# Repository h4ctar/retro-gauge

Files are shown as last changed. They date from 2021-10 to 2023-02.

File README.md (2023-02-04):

# Retro Gauge

## Introduction

This is an open source motorcycle tacho project with the following features:

- Analog tachometer
- Digital speedometer
- Odometer
- Trip meter
- Battery voltage
- Standard indicators (turn signals, oil pressure, neutral and high beam)
- Clock

It is housed in a classic round casing, with a retro looking 8 digit starburst LCD.

The toolchain is all open source; the PCB's are designed with KiCad and the case is designed in FreeCAD.

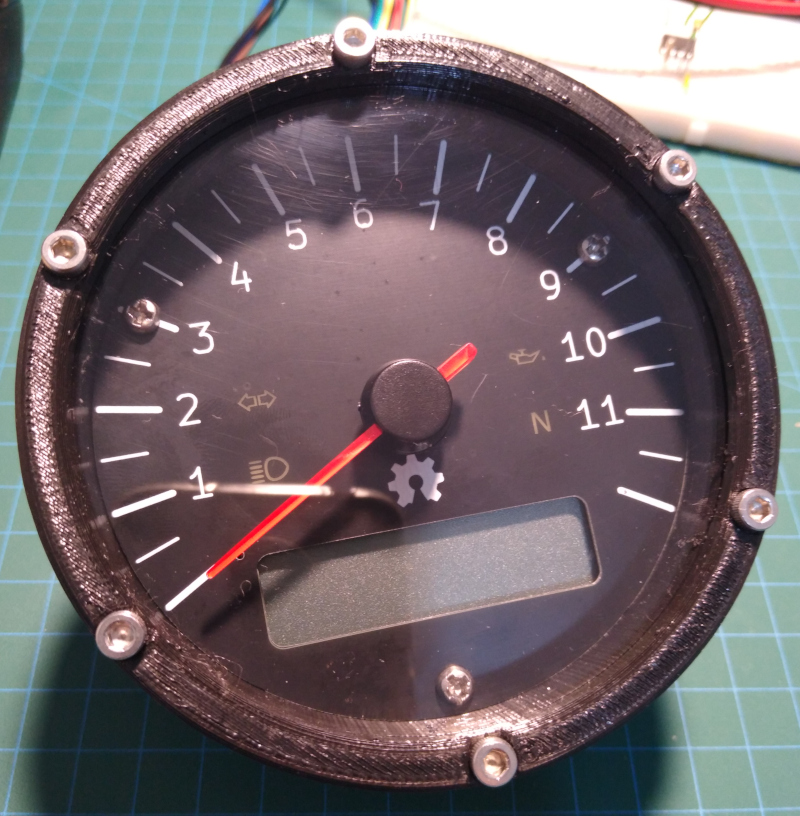
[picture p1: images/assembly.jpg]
Assembly


## System Design

The system design is simple, the only interesting decision is that the indicators all go via the microcontroller, this lets us do fun things with the indicators (test them when powered on or reuse the oil pressure indicator for other warnings).

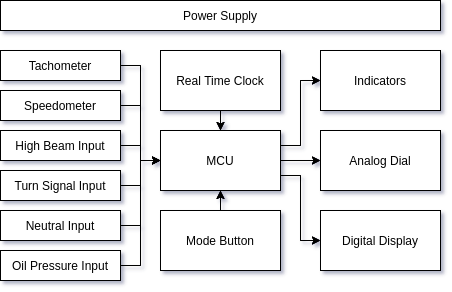
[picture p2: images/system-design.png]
System Design


## Microcontroller

An ATmega328P-PU microcontroller will be used to process all the inputs, and drive the outputs.

Here are all the required inputs and outputs:

| Function | Type | Number of pins |
| --- | --- | --- |
| Tacho | Digital input  | 1 |
| Speedo | Digital input  | 1 |
| Oil pressure | Digital input  | 1 |
| Turn signals | Digital input  | 1 |
| Neutral | Digital input  | 1 |
| High beam | Digital input  | 1 |
| Mode button | Digital input  | 1 |
| Battery voltage | Analog input | 1 |
| Stepper motor | Digital output | 4 (could be 3) |
| RBG LEDs | Digital output | 1 |
| LCD | Digital output | 3 |
| ISP | Digital IO | 3 (can be shared) |
| Real time clock | Digital IO | 2 |

For a total of 18 digital IOs and one analog input, the ATmega328P-PU has more than enough at 23 programmable IO lines.

The ATmega328P-PU also has 1024 bytes of EEPROM which can be used to store the configuration, trip and odometer values.

An external 16 MHz crystal will be used to run the ATmega328P-PU at it's fastest clock speed.

The microcontroller will be programmed with an in-circuit serial programmer (ICSP).
A bootloader doesnt need to be burned when using ICSP.

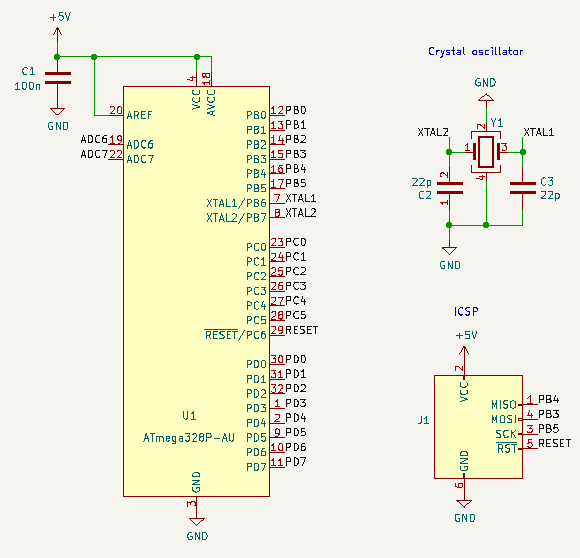
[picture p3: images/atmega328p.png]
ATmega328P


The low byte fuses configure the clock:

| Bit | Name | Description | Value |
| --- | --- | --- | ----- |
| 7 | CKDIV8 | When set, divides the clock speed by 8 | 1 |
| 6 | CKOUT  | When set, the clock pulse is output on PB0 | 1 |
| 5 | SUT1 | Sets start up delay time | 1 |
| 4 | SUT0 | | 1 |
| 3 | CKSEL3 | Sets the clock source | 1 |
| 2 | CKSEL2 | | 1 |
| 1 | CKSEL1 | | 1 |
| 0 | CKSEL0 | | 1 |

The high byte fuses:

| Bit | Name | Description | Value |
| --- | --- | --- | ----- |
| 7 | RSTDISBL | External reset disable | 1 |
| 6 | DWEN | Debug wire enable | 1 |
| 5 | SPIEN | Enable serial programming | 0 |
| 4 | WDTON | Watchdog timer always on | 1 |
| 3 | EESAVE | Preserve EEPROM memory through chip erase | 0 |
| 2 | EBOOTSZ1 | Sets the bootloder size memory | 1 |
| 1 | EBOOTSZ0 | | 1 |
| 0 | BOOTRST  | Select the reset vector | 0 |

The extended fuses:

| Bit | Name | Description | Value |
| --- | --- | --- | ----- |
| 7 | | Not used | 1 |
| 6 | | | 1 |
| 5 | | | 1 |
| 4 | | | 1 |
| 3 | | | 1 |
| 2 | BODLEVEL2 | Sets the brown-out detector level | 1 |
| 1 | BODLEVEL1 | | 0 |
| 0 | BODLEVEL0 | | 1 |

There is a simple Makefile that compiles and links the code and has targets to burn the fuses and the code.

## Power Supply

A linear voltage regulator will be used to convert the bikes rough 14V down to a smooth 5V for the rest of the system.
A smoothing capacitor is added on the bikes side to help smooth out the input before it gets to the regulator.

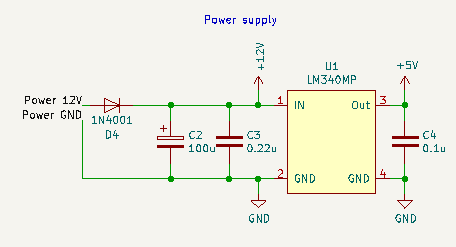
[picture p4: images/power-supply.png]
Power Supply


## Indicator Lights

There are indicator lights for low oil pressure, neutral, high beam and turn signals.

The oil pressure and neutral sensors are simple switches to ground.
So these will be directly connected to digital input pins.
I'm not sure if the internal pull ups will be good enough so there will be provision on the PCB for external pull up resistors.
There will be a diode to protect against connecting this pin to 12V on the bike.

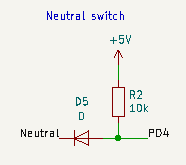
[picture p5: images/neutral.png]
Neutral


The highbeam and turn signals indicators should light up when they see 12V.
We'll use an optocoupler to give some extra protection.
The left and right turn signals need to go through diodes to stop them turning each other on.

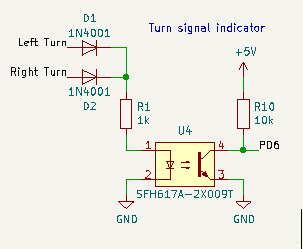
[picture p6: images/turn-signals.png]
Turn Signals


```
Diode forward voltage: 0.715V
Photodiode forward voltage: 1.3V
Photodiode forward current: 10mA
R1 = (14V - 0.715V - 1.3V) / 10mA = 1200 ohm ~= 1k ohm
```

```
CTR: 50%
Output current: 50% of 10mA = 5mA
Output voltage: 4V
R2 = (5V - 4V) / 5mA = 200 ohm
```

## Tachometer

There are a few choices for the tachometer pickup, an inductive or capacitive pickup on one of the spark plug wires, or a hall effect sensor on a rotating part of the engine.
The most robust solution is to go with the hall effect sensor, and the most universal location for it is in replacement of the mechanical drive off the camshaft of the original tachometer.

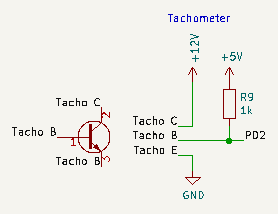
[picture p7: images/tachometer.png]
Tachometer


## Speedometer

The speedometer will also be a hall effect pickup, but will be a simpler design with a few magnets on the wheel and an NPN hall effect sensor mounted on an axel spacer.

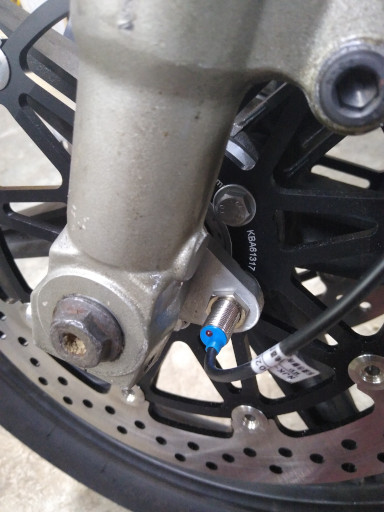
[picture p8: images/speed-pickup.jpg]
Speed Pickup


## Real Time Clock

A PCF8563T RTC module will be used to keep the time for the clock.
It will have a coin cell to keep the clock ticking when the key is off.

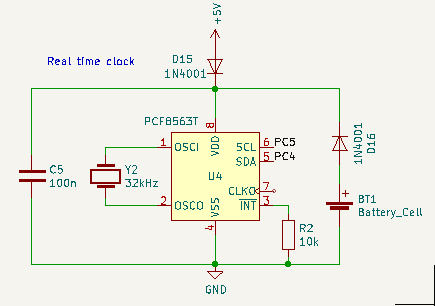
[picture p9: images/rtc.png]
RTC


## LCD

The VIM-878-DP-FC-S-LV LCD display will be used.
It is a transflective LCD so works well in both bright sunlight and at night with a backlight.
It is an 8 character 14 (plus 2) segment "starburst" display.
It has a total of (14 + 2) \* 8 = 128 segments and uses 4 backplanes.

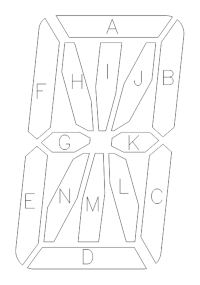
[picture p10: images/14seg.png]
LCD Segment Names


The HT1621B will be used to drive the LCD.
There are some existing Arduino libraries to interface with it.
It can drive 32 segments by 4 commons which is exactly what is required to drive the selected LCD.

The schematic of the driver to the display follows the application notes in the datasheet and is optimised for the PCB layout.
It is controlled with 3 pins that are also used by the ICSP.

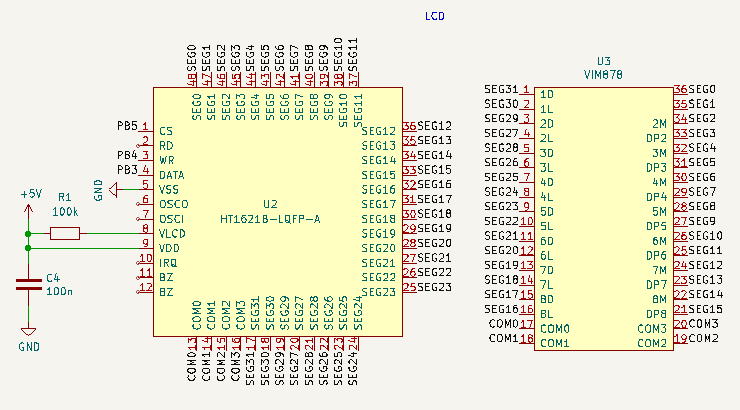
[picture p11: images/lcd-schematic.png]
LCD Schematic


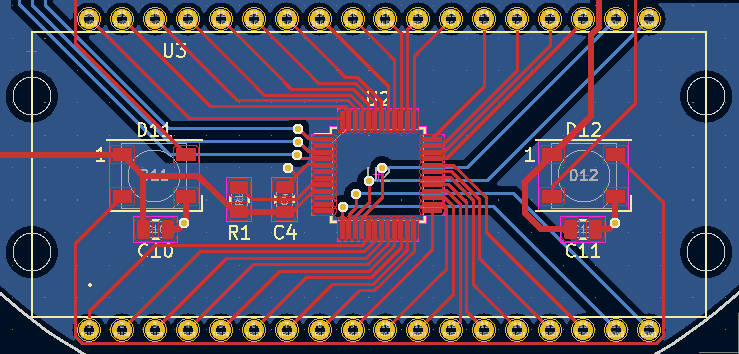
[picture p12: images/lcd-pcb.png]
LCD PCB


This table has the LCD segments from the datasheet and what memory address they are according to the PCB layout:

| LCD Pin | COM0 | COM1 | COM2 | COM3 | Memory address |
| --- | ---- | ---- | ---- | ---- | --- |
| 1 | 1D | 1E | 1F | CA1  | 31 |
| 2 | 1L | 1K | 1J | 1I | 30 |
| 3 | 2D | 2E | 2F | CA2  | 29 |
| 4 | 2L | 2K | 2J | 2I | 27 |
| 5 | 3D | 3E | 3F | CA3  | 28 |
| 6 | 3L | 3K | 3J | 3I | 26 |
| 7 | 4D | 4E | 4F | CA4  | 25 |
| 8 | 4L | 4K | 4J | 4I | 24 |
| 9 | 5D | 5E | 5F | CA5  | 23 |
| 10 | 5L | 5K | 5J | 5I | 22 |
| 11 | 6D | 6E | 6F | CA6  | 21 |
| 12 | 6L | 6K | 6J | 6I | 20 |
| 13 | 7D | 7E | 7F | CA7  | 19 |
| 14 | 7L | 7K | 7J | 7I | 18 |
| 15 | 8D | 8E | 8F | CA8  | 17 |
| 16 | 8L | 8K | 8J | 8I | 16 |
| 17 | COM0 | | | | |
| 18 | | COM1 | | | |
| 19 | | | COM2 | | |
| 20 | | | | COM3 | |
| 21 | DP8  | 8C | 8B | 8A | 15 |
| 22 | 8M | 8N | 8G | 8H | 14 |
| 23 | DP7  | 7C | 7B | 7A | 13 |
| 24 | 7M | 7N | 7G | 7H | 12 |
| 25 | DP6  | 6C | 6B | 6A | 11 |
| 26 | 6M | 6N | 6G | 6H | 10 |
| 27 | DP5  | 5C | 5B | 5A | 9 |
| 28 | 5M | 5N | 5G | 5H | 8 |
| 29 | DP4  | 4C | 4B | 4A | 7 |
| 30 | 4M | 4N | 4G | 4H | 6 |
| 31 | DP3  | 3C | 3B | 3A | 5 |
| 32 | 3M | 3N | 3G | 3H | 4 |
| 33 | DP2  | 2C | 2B | 2A | 3 |
| 34 | 2M | 2N | 2G | 2H | 2 |
| 35 | DP1  | 1C | 1B | 1A | 1 |
| 36 | 1M | 1N | 1G | 1H | 0 |

From this table we can see that each digit is powered by 4 LCD pins that map to 4 memory addresses.
For example digit 1 is LCD pins 35, 1, 2 and 36, which map to memory address' 1, 31, 30 and 0.

The font maps ASCII characters to the segments in order CA,F,E,D,I,J,K,L,A,B,C,DP,H,G,N,M.
The segments are in this order so the nibbles match the memory layout of the driver.

The address mapping maps digits to the 4 memory addresses that the font nibbles should be written to.

| Digit | Address' |
| ----- | --- |
| 1 |  1,31,30, 0|
| 2 |  3,29,27, 2|
| 3 |  5,28,26, 4|
| 4 |  7,25,24, 6|
| 5 |  9,23,22, 8|
| 6 | 11,21,20,10|
| 7 | 13,19,18,12|
| 8 | 15,17,16,14|

This font table and address mapping should be enough to display text on the LCD.

## Stepper motor

The X27.168 stepper motor will be used, it is designed for gauges and can be directly driven from a microcontroller.

People on the internet say that clamping diodes are required, so they will be added.

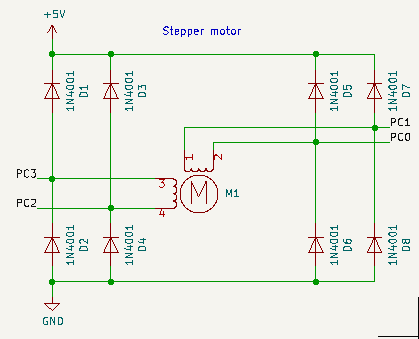
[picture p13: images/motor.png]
Motor


The X25 datasheet shows the required pattern to step the motor.

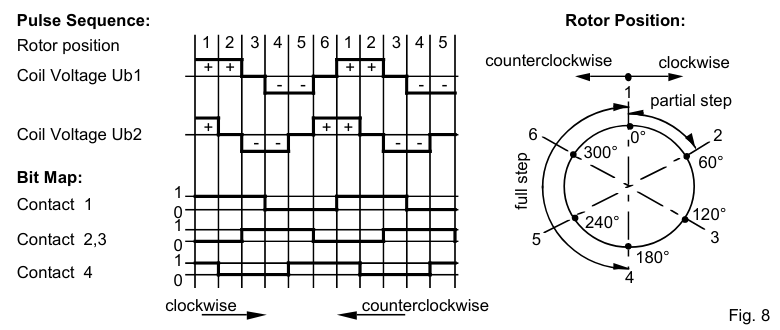
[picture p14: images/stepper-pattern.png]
Step Pattern


## Indicators

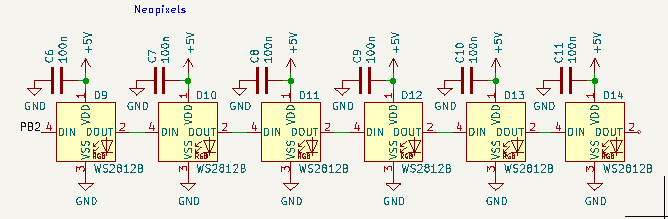
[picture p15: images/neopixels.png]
Neopixels


## PCB Design

There are three PCBs: the main board, the sensor board and the face board.
The boards are stacked using standoffs and are connected together with 2.54mm stacking header pins.

The main board has the microcontroller, stepper motor, LCD, real time clock and indicators.
The sensor board has the power supply and the signal conditioning.
The face board is the dial face and has transparent icons for the indicators.

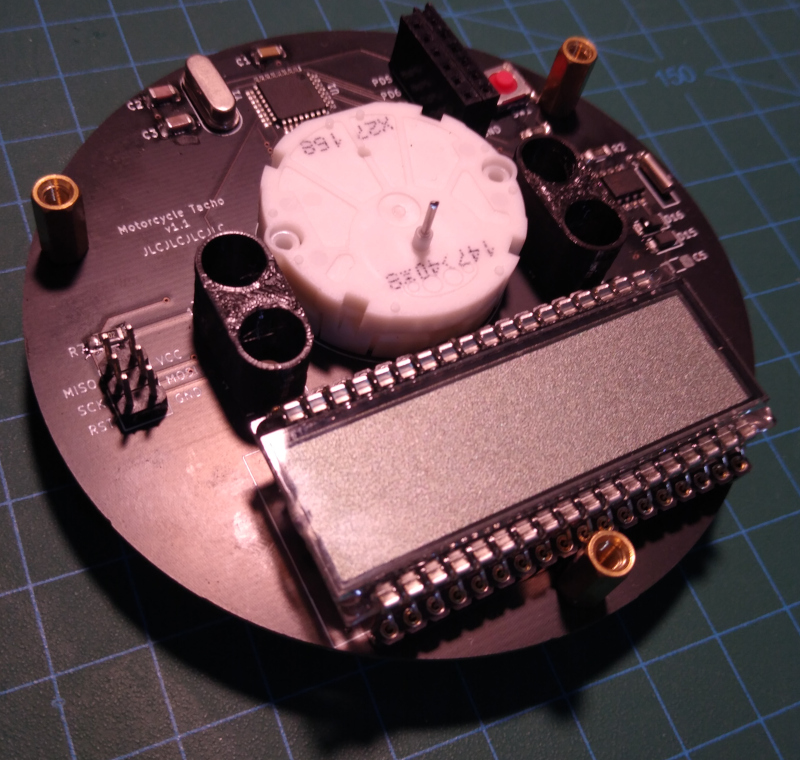
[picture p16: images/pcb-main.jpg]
Main PCB


## Case Design

The case is 3D printed out of ASA.

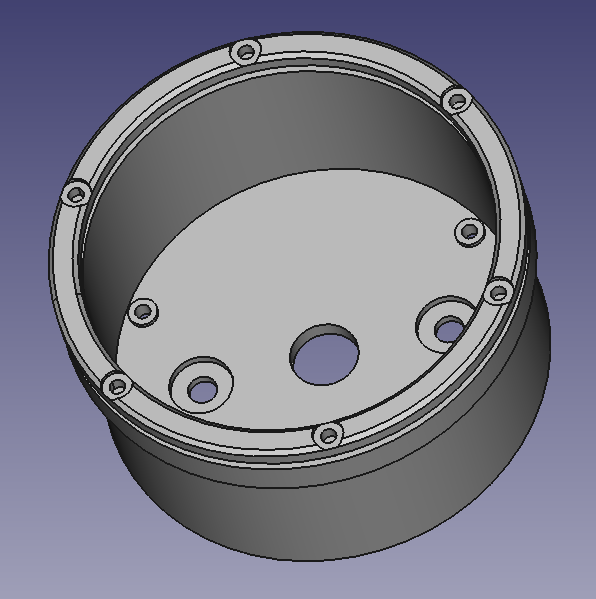
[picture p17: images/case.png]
Case


## EEPROM

The ODO, trip and configuration will be stored in EEPROM.

EEPROM has like 100,000 writes before it wears out, so in order to be able to store the ODO and trip we will need to be able to rotate to new address'.
To do this we will have a table at the start of the EEPROM that stores the address of each value and if the EEPROM gets corrupt we will find a new place to store it and update the table.

| Address | Size | Description |
| --- | ---- | --- |
| 0 | 8 | ODO Address |
| 1 | 8 | Trip Address |
| 2 | 8 | Wheel diameter |
| 15 | 8 | Next available address |
| 16 | 32 | ODO value |
| 20 | 32 | Trip value |

## Firmware

The source code is in the `firmware/src` directory.

There is a makefile with a default target to compile and link the source into a hex file; a `burn` target to burn this hex to the micro and a `fuses` target to write the fuses.
It is configured to use avrdude and a usbtiny programmer to talk to the microcontroller, but it should be possible to modify it to use other methods.
The code is compiled with clang.
There is a compile_flags.txt file that is used to configure a language server so that Vim or Visual Studio Code can give nice completion and code navigation.

On Arch linux I install the following tools and dependencies:

 * llvm
 * clang
 * avrdude
 * avr-libc
 * lib32-glibc

## Datasheets

 * [ATmega328p](https://ww1.microchip.com/downloads/en/DeviceDoc/Atmel-7810-Automotive-Microcontrollers-ATmega328P_Datasheet.pdf)
 * [HT1621B](https://www.holtek.com/documents/10179/116711/HT1621v321.pdf)
 * [WS2812B](https://www.digikey.com.au/en/datasheets/parallaxinc/parallax-inc-28085-ws2812b-rgb-led-datasheet)

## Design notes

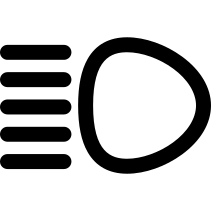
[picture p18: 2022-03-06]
images/indicators/high-beam-svgrepo-com.png

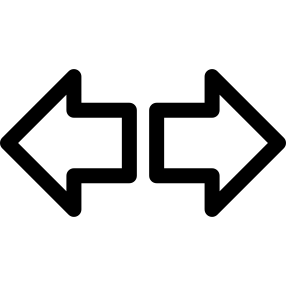
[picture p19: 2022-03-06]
images/indicators/turn-signals-svgrepo-com.png

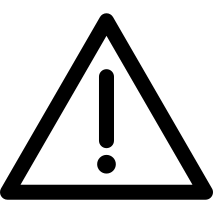
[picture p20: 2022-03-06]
images/indicators/warning-svgrepo-com-1.png

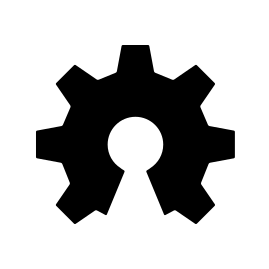
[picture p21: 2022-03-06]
images/indicators/oshw.png

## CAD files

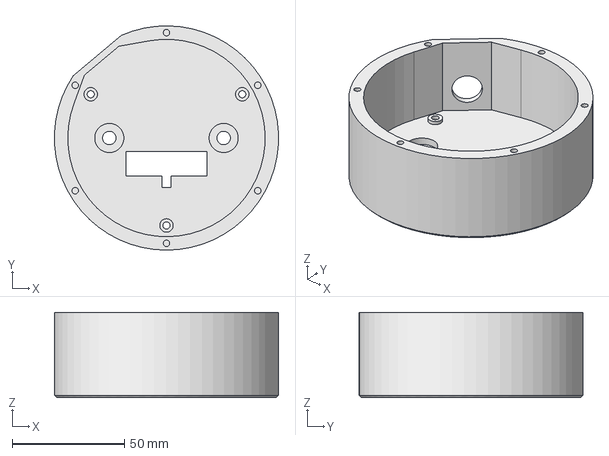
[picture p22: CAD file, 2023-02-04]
3d-models/case.FCStd
99.9 x 100.0 x 38.0 mm

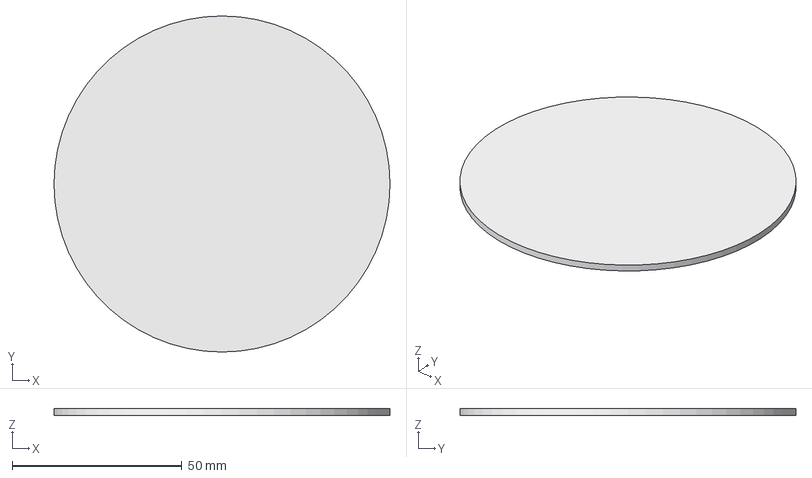
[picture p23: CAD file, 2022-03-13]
3d-models/glass.FCStd
99.0 x 99.0 x 2.00 mm

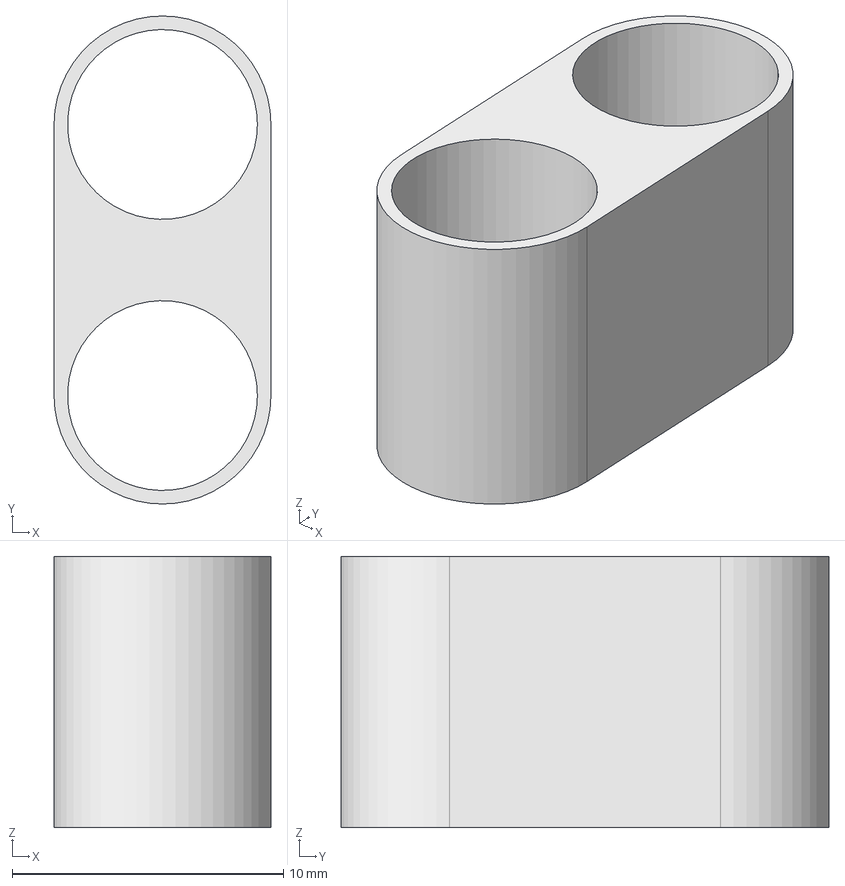
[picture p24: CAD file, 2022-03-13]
3d-models/led-shield.FCStd
8.00 x 18.0 x 10.0 mm

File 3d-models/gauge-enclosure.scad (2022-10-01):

$fn=64;
overlap=0.001;

inner_height=40;
inner_radius=43.5;
wall_thickness=6.5;
base_thickness=4;

standoff_height=2;
standoff_outer_radius=3;

pcb_mounting_hole_radius=1.5;

difference() {
    union() {
        difference() {
            // The main body
            cylinder(inner_height + base_thickness, inner_radius + wall_thickness, inner_radius + wall_thickness);
            // The hole in the middle
            translate([0, 0, base_thickness]) {
                cylinder(inner_height + overlap, inner_radius, inner_radius);
            };
        };
        // The PCB standoffs
        translate([-33.78, 19.2, 0]) {
            cylinder(base_thickness + standoff_height, standoff_outer_radius, standoff_outer_radius);
        };
        translate([33.78, 19.2, 0]) {
            cylinder(base_thickness + standoff_height, standoff_outer_radius, standoff_outer_radius);
        };
        translate([0, -39, 0]) {
            cylinder(base_thickness + standoff_height, standoff_outer_radius, standoff_outer_radius);
        };
    };
    // The face plate screw holes
    for (i = [0 : 60 : 360]) {
        rotate([0, 0, i]) {
            translate([0, 46.5, 32]) {
                cylinder(10, 1.3, 1.3);
            };
        }
    }
    // The PCB screw holes
    translate([-33.78, 19.2, -1]) {
        cylinder(10, pcb_mounting_hole_radius, pcb_mounting_hole_radius);
    };
    translate([33.78, 19.2, -1]) {
        cylinder(10, pcb_mounting_hole_radius, pcb_mounting_hole_radius);
    };
    translate([0, -39, -1]) {
        cylinder(10, pcb_mounting_hole_radius, pcb_mounting_hole_radius);
    };
    // The cable grommet hole
    translate([0, 0, -1]) {
        cylinder(10, 7.5, 7.5);
    };
    translate([0, 0, 1.5]) {
        cylinder(10, 10, 10);
    };
    // The mounting bolt holes
    translate([-26, 0, -1]) {
        cylinder(10, 3, 3);
    };
    translate([-26, 0, 2]) {
        cylinder(10, 6.5, 6.5);
    };
    translate([26, 0, -1]) {
        cylinder(10, 3, 3);
    };
    translate([26, 0, 2]) {
        cylinder(10, 6.5, 6.5);
    };
    // The button hole
    rotate([0, 0, 130]) {
        translate([46.5, 0, 13]) {
            rotate([0, 90, 0]) {
                union() {
                    translate([0, 0, 5]) {
                        cube([100, 18, 4.6], true);
                    };
                    cylinder(10, 6, 6, true);
                    translate([0, 0, -3]) {
                        cube([18, 18, 4], true);
                    };
                };
            };
        };
    };
};   
  

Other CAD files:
3d-models/pcb-outline.FCStd

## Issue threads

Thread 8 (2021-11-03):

Stacking through hole pin headers

h4ctar, 2021-11-03:
Should be a bit lower profile

And it could be easier to trace with the same plug between the face and the main and then sensor pcbs

h4ctar, 2021-11-27:
Done

Closed 2021-11-27.

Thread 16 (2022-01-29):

TWI pull up resistors

h4ctar, 2022-01-29:
https://embedds.com/programming-avr-i2c-interface/

h4ctar, 2022-01-30:
Not needed as there are built in pull ups

Closed 2022-01-30.

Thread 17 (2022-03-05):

Move speedo and tacho to interrupt pins

h4ctar, 2022-03-05:
The speedo is currently done with a pin change interrupt instead of a hardware interrupt.

Change it to one of the two hardware interrupt pins if possible.

Closed 2022-09-17.

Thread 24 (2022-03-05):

Shorter power smoothing capacitor

h4ctar, 2022-03-05:

Closed 2022-03-07.

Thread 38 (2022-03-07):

Bigger RTC backup cell

h4ctar, 2022-03-07:

h4ctar, 2022-03-07:
Currently it has a CR1220 which is 38mAh.
The chip draw 0.25uA in backup.
So the battery will last 16 years, I think this is OK.

Closed 2022-03-07.

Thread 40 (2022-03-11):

Fix 3D models

h4ctar, 2022-03-11:
All 3D models are missing since the upgrade to kicad 6

Closed 2022-09-17.

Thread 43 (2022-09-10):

Speed sensor spikes

h4ctar, 2022-09-10:
When the engine is running the speedo spikes

h4ctar, 2022-09-10:
Fixed by reducing the 10k pull up resistor to 1k.

This will result in a current draw of 5V/1kohm = 5mA which is still fine, the NJK-5002C NPN type hall effect sensor load current is 150mA so it should be able to pull it down.

Closed 2022-09-10.

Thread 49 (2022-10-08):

Fix octocoupler footprint

h4ctar, 2022-10-08:

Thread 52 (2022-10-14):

Fix crystal oscillator wiring

h4ctar, 2022-10-14:

h4ctar, 2022-10-14:
The wrong pins are used.
It needs a ground.
Should only be 9pF.

h4ctar, 2022-10-14:
Actually, maybe they should be 12pF.

Closed 2022-10-14.

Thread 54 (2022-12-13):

Create pipeline

h4ctar, 2022-12-13:
Create a GitHub pipeline to:
- Generate STL from FreeCad models
- Generate BOM
- Generate POS
- Generate Gerbers
- Generate Drill
- Build ELF

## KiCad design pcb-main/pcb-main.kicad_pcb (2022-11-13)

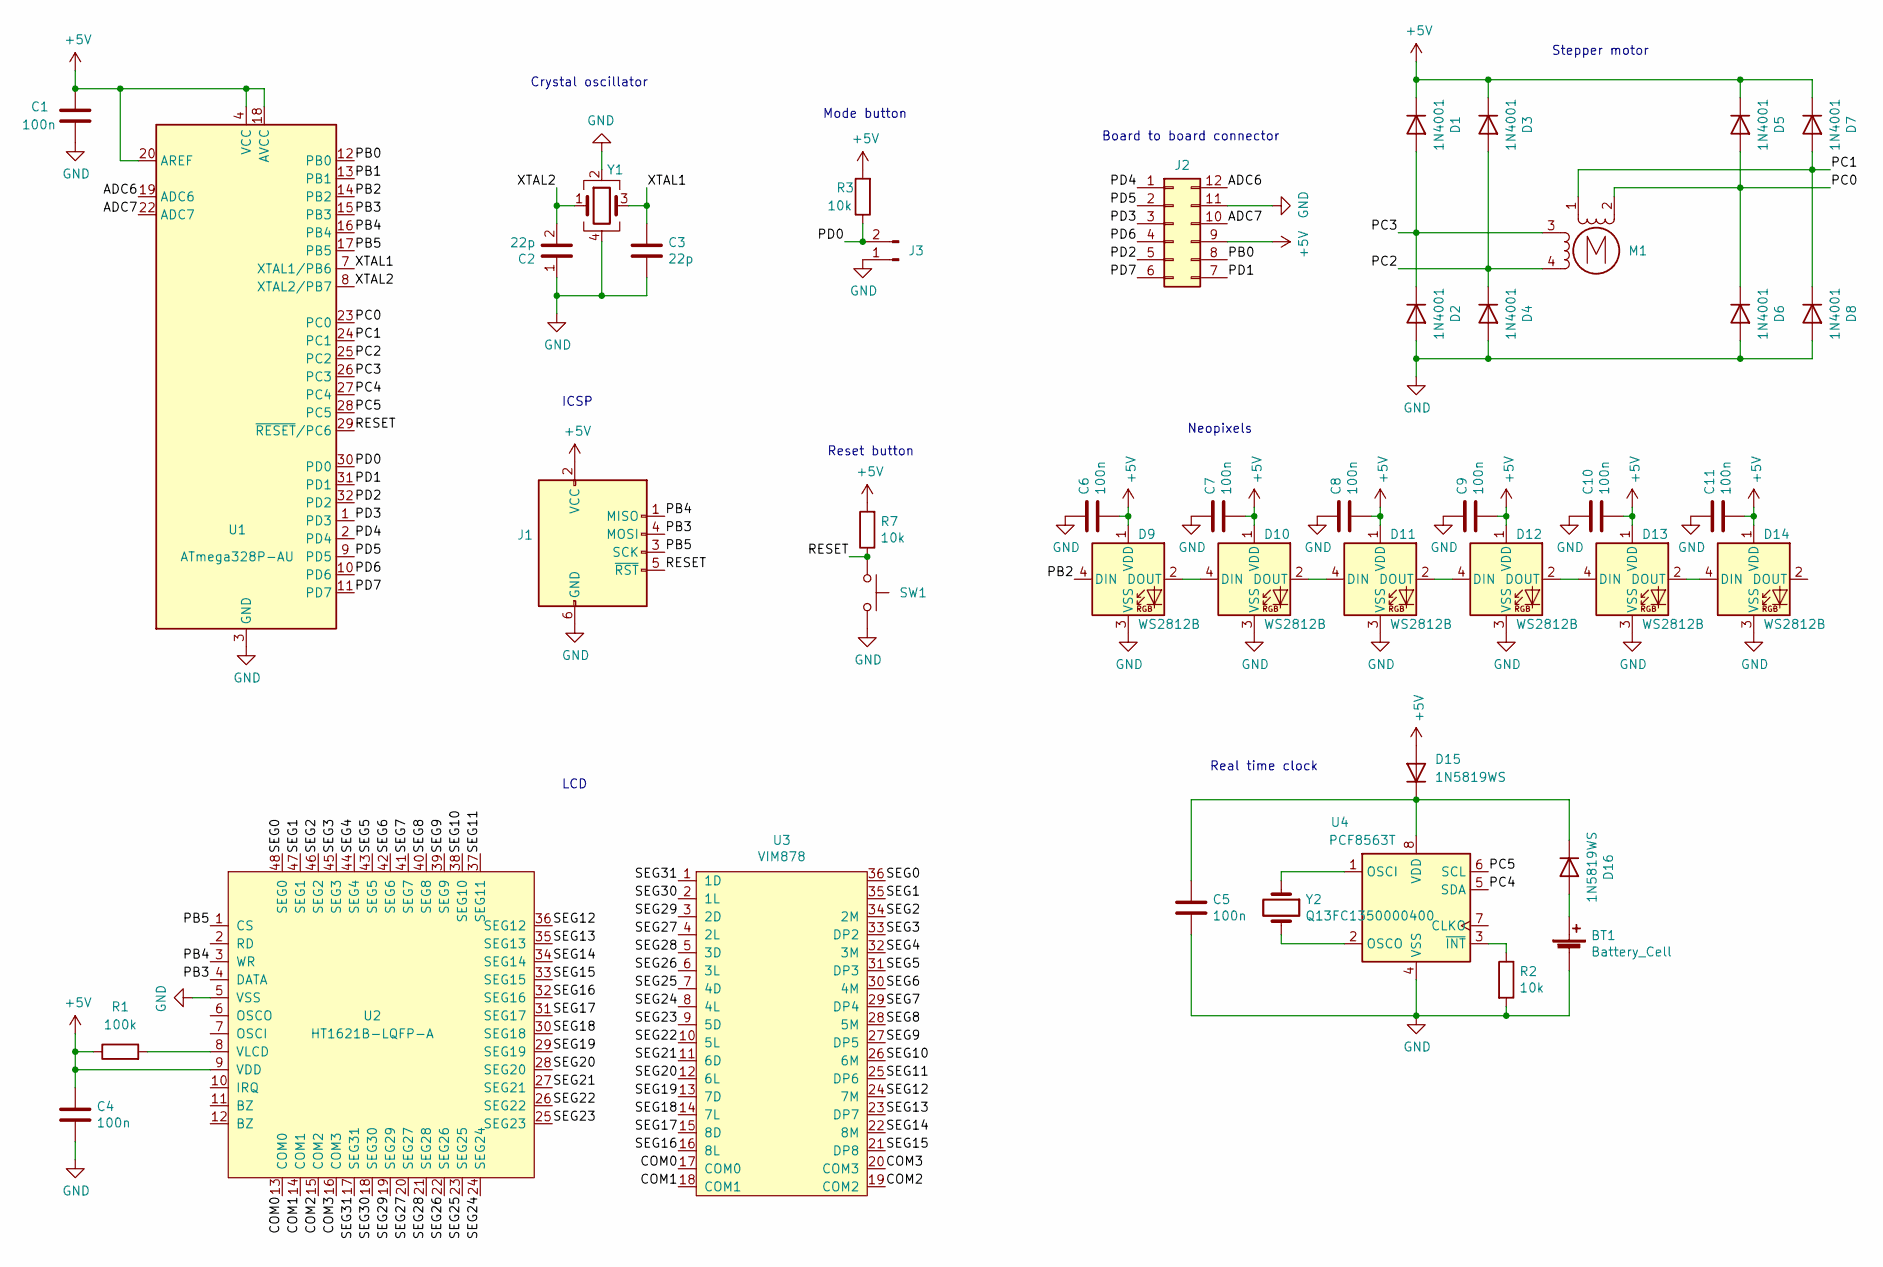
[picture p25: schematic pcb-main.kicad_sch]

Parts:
BT1: Battery_Cell; CR1220
C1, C4, C5, C6, C7, C8, C9, C10, C11: 100n; C_0805_2012Metric; LCSC C49678
C2, C3: 22p; C_0805_2012Metric; LCSC C1804
D1, D2, D3, D4, D5, D6, D7, D8: 1N4001; D_1206_3216Metric_Pad1.42x1.75mm_HandSolder
D9, D10, D11, D12, D13, D14: WS2812B; LED_WS2812B_PLCC4_5.0x5.0mm_P3.2mm; LCSC C2761795
D15, D16: 1N5819WS; D_SOD-323; LCSC C191023
J1: AVR-ISP-6; PinHeader_2x03_P2.54mm_Vertical
J2: Conn_02x06_Counter_Clockwise; PinHeader_2x06_P2.00mm_Vertical
J3: Conn_01x02_Male; JST_PH_S2B-PH-K_1x02_P2.00mm_Horizontal
M1: Stepper_Motor; X27.168
R1: 100k; R_0805_2012Metric; LCSC C149504
R2, R3, R7: 10k; R_0805_2012Metric; LCSC C17414
SW1: SW_Push; SW_SPST_TL3342; LCSC C318884
U1: ATmega328P-AU; TQFP-32_7x7mm_P0.8mm; LCSC C14877
U2: HT1621B-LQFP-A; LQFP-48_7x7mm_P0.5mm; LCSC C7532
U3: VIM878
U4: PCF8563T; SOIC-8_3.9x4.9mm_P1.27mm; LCSC C7440
Y1: X322516MLB4SI; Crystal_SMD_3225-4Pin_3.2x2.5mm; LCSC C13738
Y2: Q13FC1350000400; Crystal_SMD_3215-2Pin_3.2x1.5mm; LCSC C32346

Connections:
+5V: C1.1, C4.1, C6.2, C7.2, C8.2, C9.2, C10.2, C11.2, D1.1 (K), D3.1 (K), D5.1 (K), D7.1 (K), D9.1 (VDD), D10.1 (VDD), D11.1 (VDD), D12.1 (VDD), D13.1 (VDD), D14.1 (VDD), D15.2 (A), J1.2 (VCC), J2.9, R1.1, R3.2, R7.2, U1.4 (VCC), U1.6 (VCC), U1.18 (AVCC), U1.20 (AREF), U2.9 (VDD)
/ADC6: J2.12, U1.19 (ADC6)
/ADC7: J2.10, U1.22 (ADC7)
/COM0: U2.13 (COM0), U3.17 (COM0)
/COM1: U2.14 (COM1), U3.18 (COM1)
/COM2: U2.15 (COM2), U3.19 (COM2)
/COM3: U2.16 (COM3), U3.20 (COM3)
/PB0: J2.8, U1.12 (PB0)
/PB1: U1.13 (PB1)
/PB2: D9.4 (DIN), U1.14 (PB2)
/PB3: J1.4 (MOSI), U1.15 (PB3), U2.4 (DATA)
/PB4: J1.1 (MISO), U1.16 (PB4), U2.3 (WR)
/PB5: J1.3 (SCK), U1.17 (PB5), U2.1 (CS)
/PC0: D5.2 (A), D6.1 (K), M1.2 (-), U1.23 (PC0)
/PC1: D7.2 (A), D8.1 (K), M1.1, U1.24 (PC1)
/PC2: D3.2 (A), D4.1 (K), M1.4, U1.25 (PC2)
/PC3: D1.2 (A), D2.1 (K), M1.3, U1.26 (PC3)
/PC4: U1.27 (PC4), U4.5 (SDA)
/PC5: U1.28 (PC5), U4.6 (SCL)
/PD0: J3.2, R3.1, U1.30 (PD0)
/PD1: J2.7, U1.31 (PD1)
/PD2: J2.5, U1.32 (PD2)
/PD3: J2.3, U1.1 (PD3)
/PD4: J2.1, U1.2 (PD4)
/PD5: J2.2, U1.9 (PD5)
/PD6: J2.4, U1.10 (PD6)
/PD7: J2.6, U1.11 (PD7)
/RESET: J1.5 (~RST), R7.1, SW1.1, U1.29 (~RESET/PC6)
/SEG0: U2.48 (SEG0), U3.36
/SEG1: U2.47 (SEG1), U3.35
/SEG2: U2.46 (SEG2), U3.34 (2M)
/SEG3: U2.45 (SEG3), U3.33 (DP2)
/SEG4: U2.44 (SEG4), U3.32 (3M)
/SEG5: U2.43 (SEG5), U3.31 (DP3)
/SEG6: U2.42 (SEG6), U3.30 (4M)
/SEG7: U2.41 (SEG7), U3.29 (DP4)
/SEG8: U2.40 (SEG8), U3.28 (5M)
/SEG9: U2.39 (SEG9), U3.27 (DP5)
/SEG10: U2.38 (SEG10), U3.26 (6M)
/SEG11: U2.37 (SEG11), U3.25 (DP6)
/SEG12: U2.36 (SEG12), U3.24 (7M)
/SEG13: U2.35 (SEG13), U3.23 (DP7)
/SEG14: U2.34 (SEG14), U3.22 (8M)
/SEG15: U2.33 (SEG15), U3.21 (DP8)
/SEG16: U2.32 (SEG16), U3.16 (8L)
/SEG17: U2.31 (SEG17), U3.15 (8D)
/SEG18: U2.30 (SEG18), U3.14 (7L)
/SEG19: U2.29 (SEG19), U3.13 (7D)
/SEG20: U2.28 (SEG20), U3.12 (6L)
/SEG21: U2.27 (SEG21), U3.11 (6D)
/SEG22: U2.26 (SEG22), U3.10 (5L)
/SEG23: U2.25 (SEG23), U3.9 (5D)
/SEG24: U2.24 (SEG24), U3.8 (4L)
/SEG25: U2.23 (SEG25), U3.7 (4D)
/SEG26: U2.22 (SEG26), U3.6 (3L)
/SEG27: U2.20 (SEG27), U3.4 (2L)
/SEG28: U2.21 (SEG28), U3.5 (3D)
/SEG29: U2.19 (SEG29), U3.3 (2D)
/SEG30: U2.18 (SEG30), U3.2 (1L)
/SEG31: U2.17 (SEG31), U3.1 (1D)
/XTAL1: C3.1, U1.7 (XTAL1/PB6), Y1.3
/XTAL2: C2.2, U1.8 (XTAL2/PB7), Y1.1
GND: BT1.2 (-), C1.2, C2.1, C3.2, C4.2, C5.2, C6.1, C7.1, C8.1, C9.1, C10.1, C11.1, D2.2 (A), D4.2 (A), D6.2 (A), D8.2 (A), D9.3 (VSS), D10.3 (VSS), D11.3 (VSS), D12.3 (VSS), D13.3 (VSS), D14.3 (VSS), J1.6 (GND), J2.11, J3.1, R2.2, SW1.2, U1.3 (GND), U1.5 (GND), U1.21 (GND), U2.5 (VSS), U4.4 (VSS), Y1.2, Y1.4
unnamed: BT1.1 (+), D16.2 (A)
unnamed: C5.1, D15.1 (K), D16.1 (K), U4.8 (VDD)
unnamed: D10.2 (DOUT), D11.4 (DIN)
unnamed: D9.2 (DOUT), D10.4 (DIN)
unnamed: D11.2 (DOUT), D12.4 (DIN)
unnamed: D12.2 (DOUT), D13.4 (DIN)
unnamed: D13.2 (DOUT), D14.4 (DIN)
unnamed: R1.2, U2.8 (VLCD)
unnamed: R2.1, U4.3 (~INT)
unnamed: U4.1 (OSCI), Y2.1
unnamed: U4.2 (OSCO), Y2.2

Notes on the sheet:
Stepper motor
Reset button
Neopixels
ICSP
Mode button
Real time clock
Board to board connector
LCD
Crystal oscillator

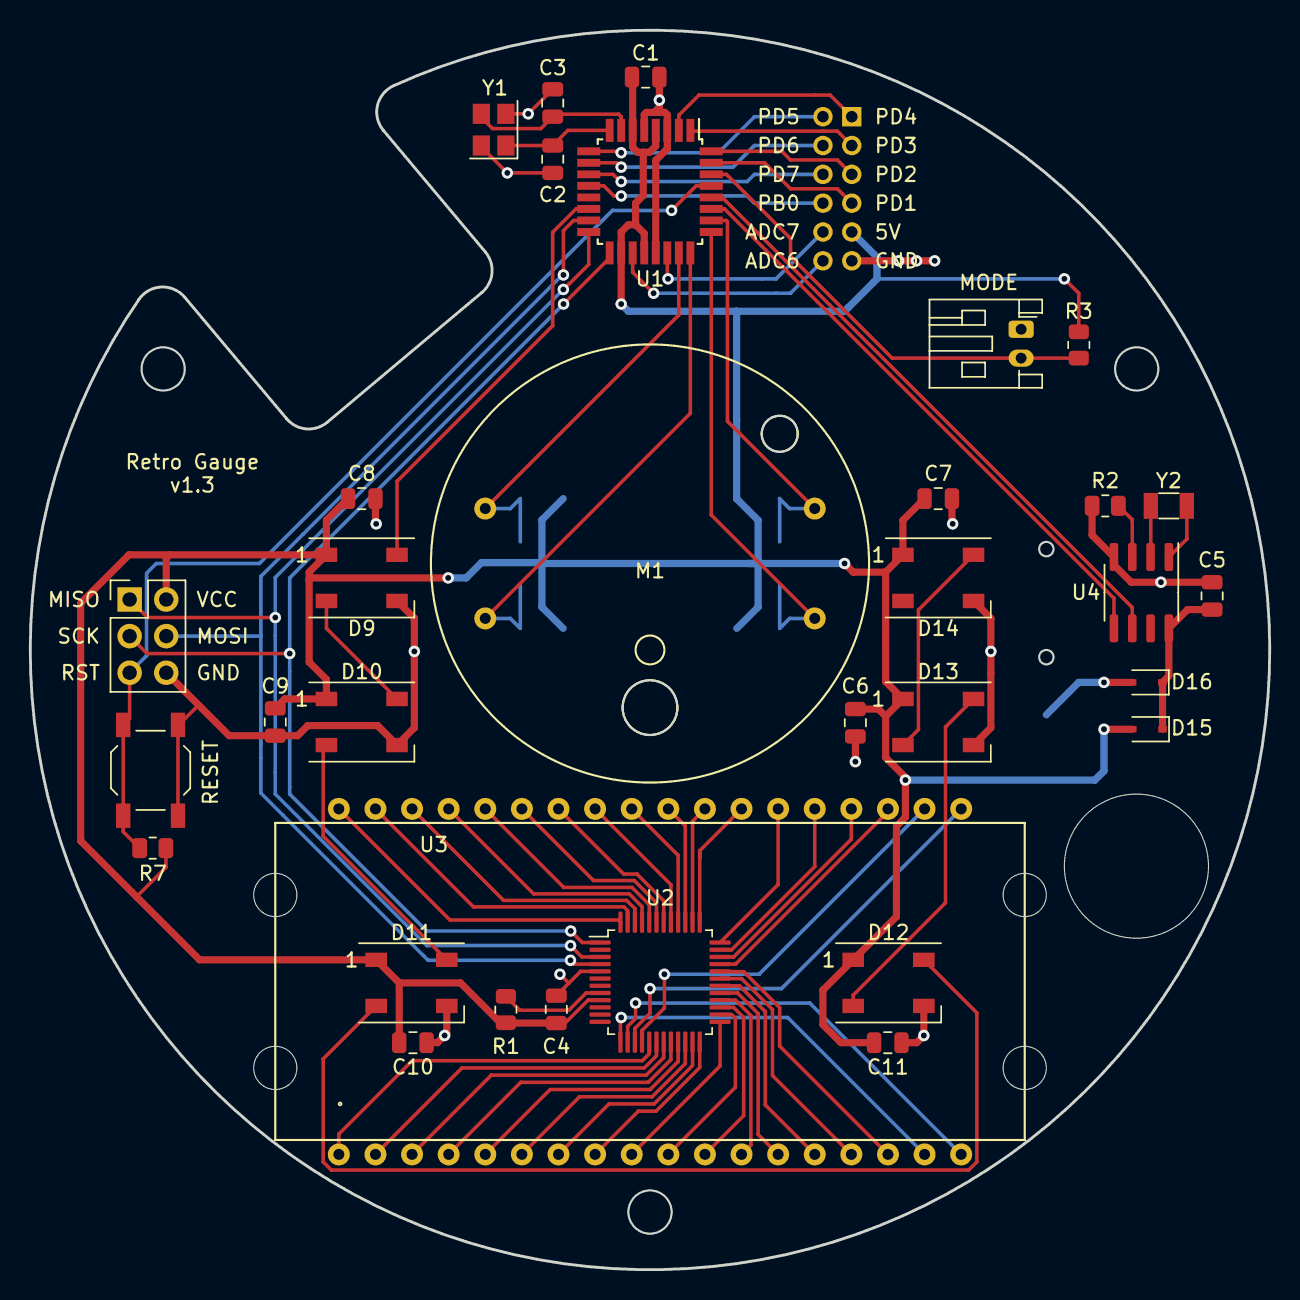
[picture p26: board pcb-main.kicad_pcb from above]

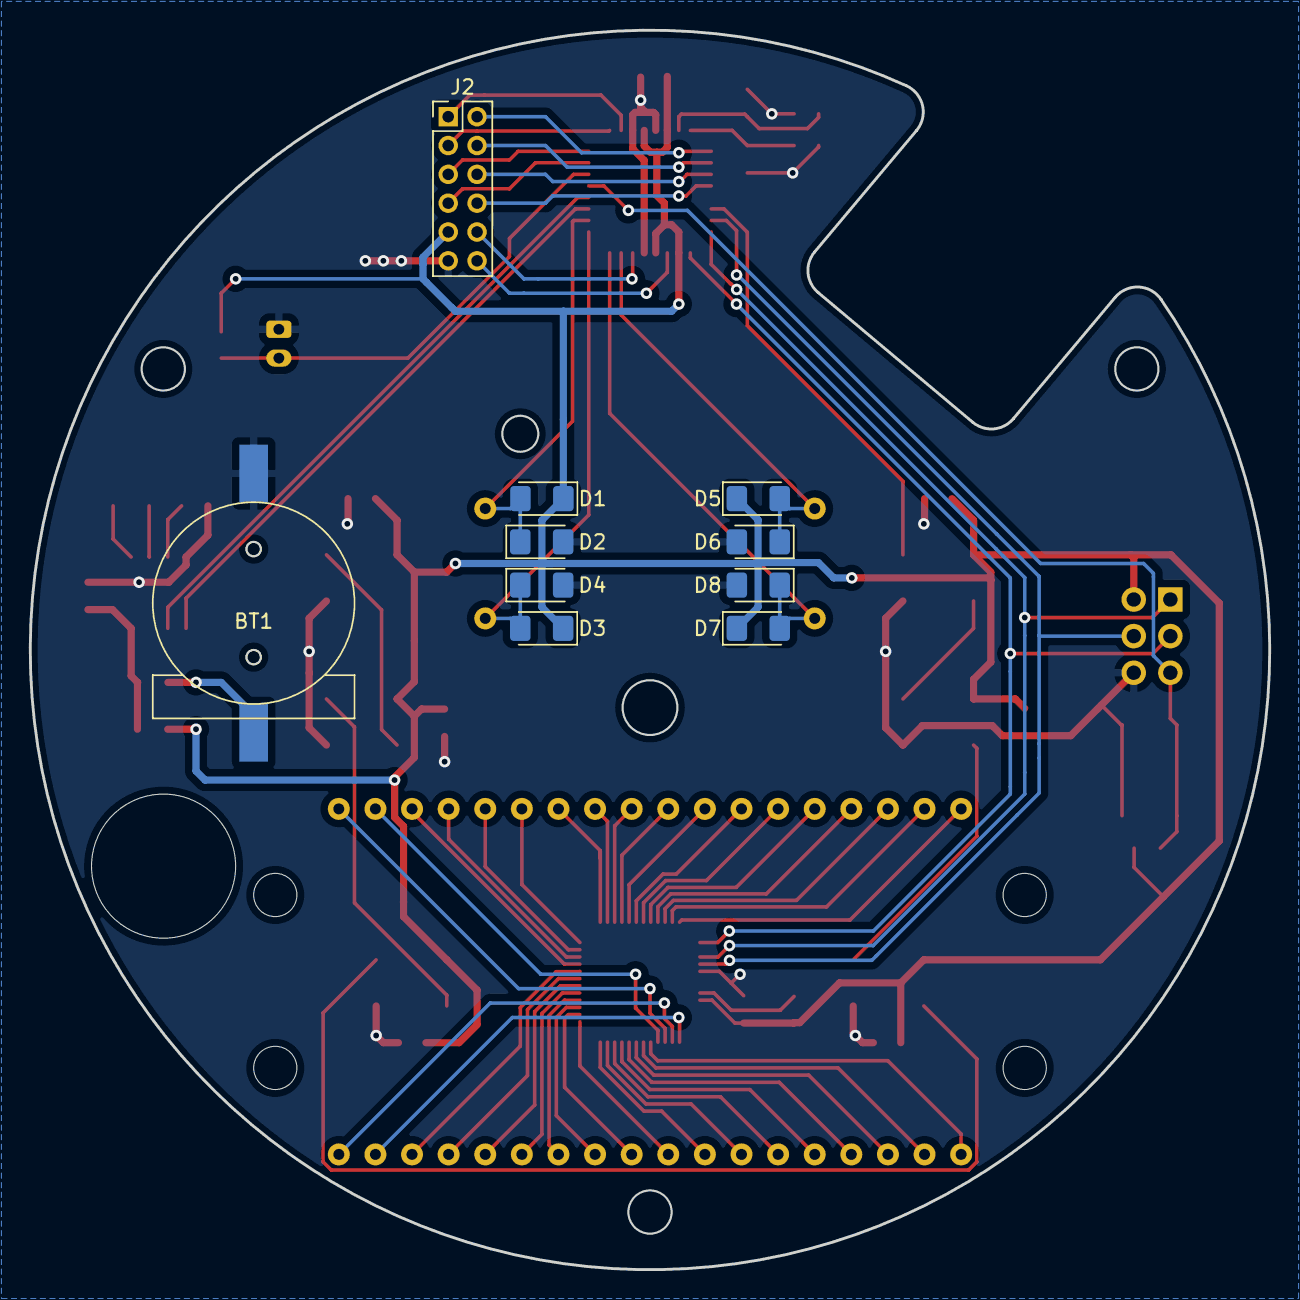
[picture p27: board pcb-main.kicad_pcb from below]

Board: 2 copper layers, 86.0 x 86.0 mm, 43 parts (10 on the bottom side), 73 nets.

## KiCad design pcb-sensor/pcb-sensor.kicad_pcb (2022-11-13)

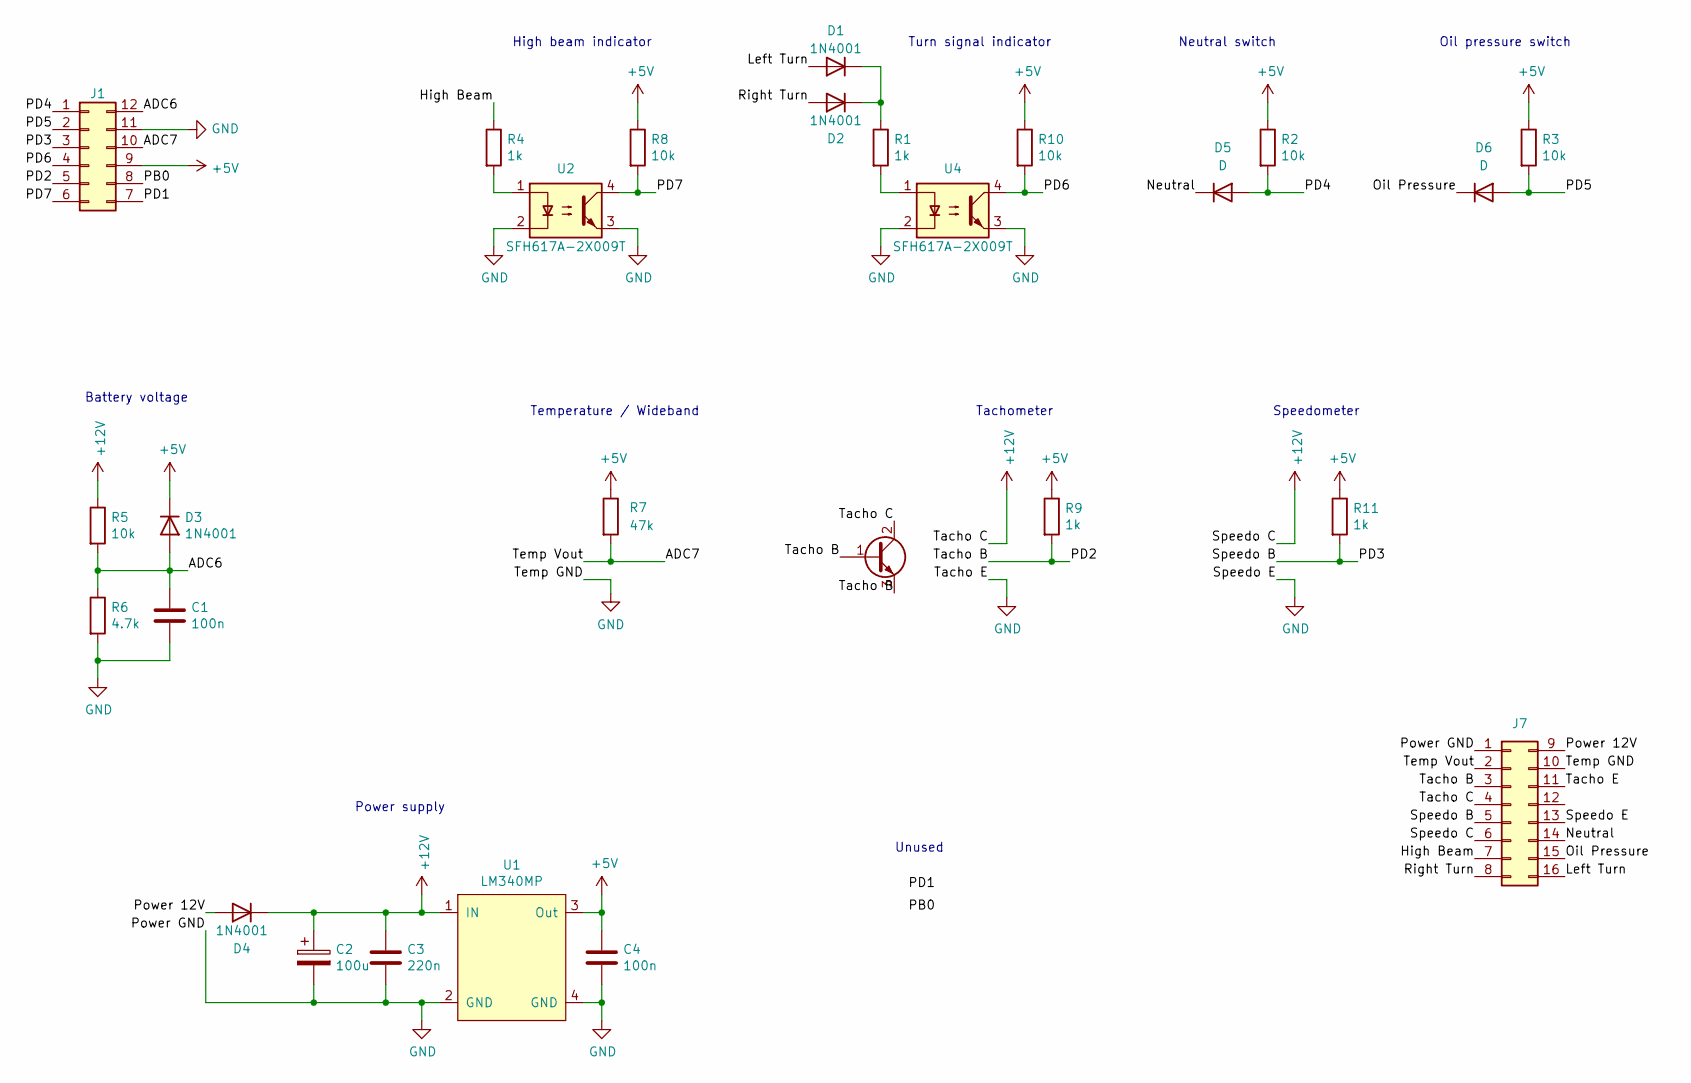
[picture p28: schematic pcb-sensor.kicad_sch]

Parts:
C1, C4: 100n; C_1206_3216Metric_Pad1.33x1.80mm_HandSolder
C2: 100u; CP_Radial_D8.0mm_P3.80mm
C3: 220n; C_1206_3216Metric_Pad1.33x1.80mm_HandSolder
D1, D2, D3, D4: 1N4001; D_1206_3216Metric_Pad1.42x1.75mm_HandSolder
D5, D6: D; D_1206_3216Metric_Pad1.42x1.75mm_HandSolder
J1: Conn_02x06_Counter_Clockwise; PinSocket_2x06_P2.00mm_Vertical
J7: Conn_02x08_Top_Bottom; Molex_Mini-Fit_Jr_5566-16A_2x08_P4.20mm_Vertical
R1, R4, R9, R11: 1k; R_1206_3216Metric_Pad1.30x1.75mm_HandSolder
R2, R3, R5, R8, R10: 10k; R_1206_3216Metric_Pad1.30x1.75mm_HandSolder
R6: 4.7k; R_1206_3216Metric_Pad1.30x1.75mm_HandSolder
R7: 47k; R_1206_3216Metric_Pad1.30x1.75mm_HandSolder
U1: LM340MP; SOT-223
U2, U4: SFH617A-2X009T; SMDIP-4_W7.62mm

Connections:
+5V: C4.1, D3.1 (K), J1.9, R2.1, R3.1, R7.1, R8.1, R9.1, R10.1, R11.1, U1.3 (Out)
+12V: C2.1, C3.1, D4.1 (K), J7.4, J7.6, R5.1, U1.1 (IN)
/ADC6: C1.1, D3.2 (A), J1.12, R5.2, R6.1
/High Beam: J7.7, R4.1
/Left Turn: D1.2 (A), J7.16
/Neutral: D5.1 (K), J7.14
/Oil Pressure: D6.1 (K), J7.15
/PB0: J1.8
/PD1: J1.7
/PD4: D5.2 (A), J1.1, R2.2
/PD5: D6.2 (A), J1.2, R3.2
/PD6: J1.4, R10.2, U4.4
/PD7: J1.6, R8.2, U2.4
/Power 12V: D4.2 (A), J7.9
/Right Turn: D2.2 (A), J7.8
/Speedo B: J1.3, J7.5, R11.2
/Tacho B: J1.5, J7.3, R9.2
/Temp Vout: J1.10, J7.2, R7.2
GND: C1.2, C2.2, C3.2, C4.2, J1.11, J7.1, J7.10, J7.11, J7.13, R6.2, U1.2 (GND), U1.4 (GND), U2.2, U2.3, U4.2, U4.3
unnamed: D1.1 (K), D2.1 (K), R1.1
unnamed: R1.2, U4.1
unnamed: R4.2, U2.1

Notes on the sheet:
Tachometer
Neutral switch
Unused
High beam indicator
Power supply
Battery voltage
Temperature / Wideband
Turn signal indicator
Oil pressure switch
Speedometer

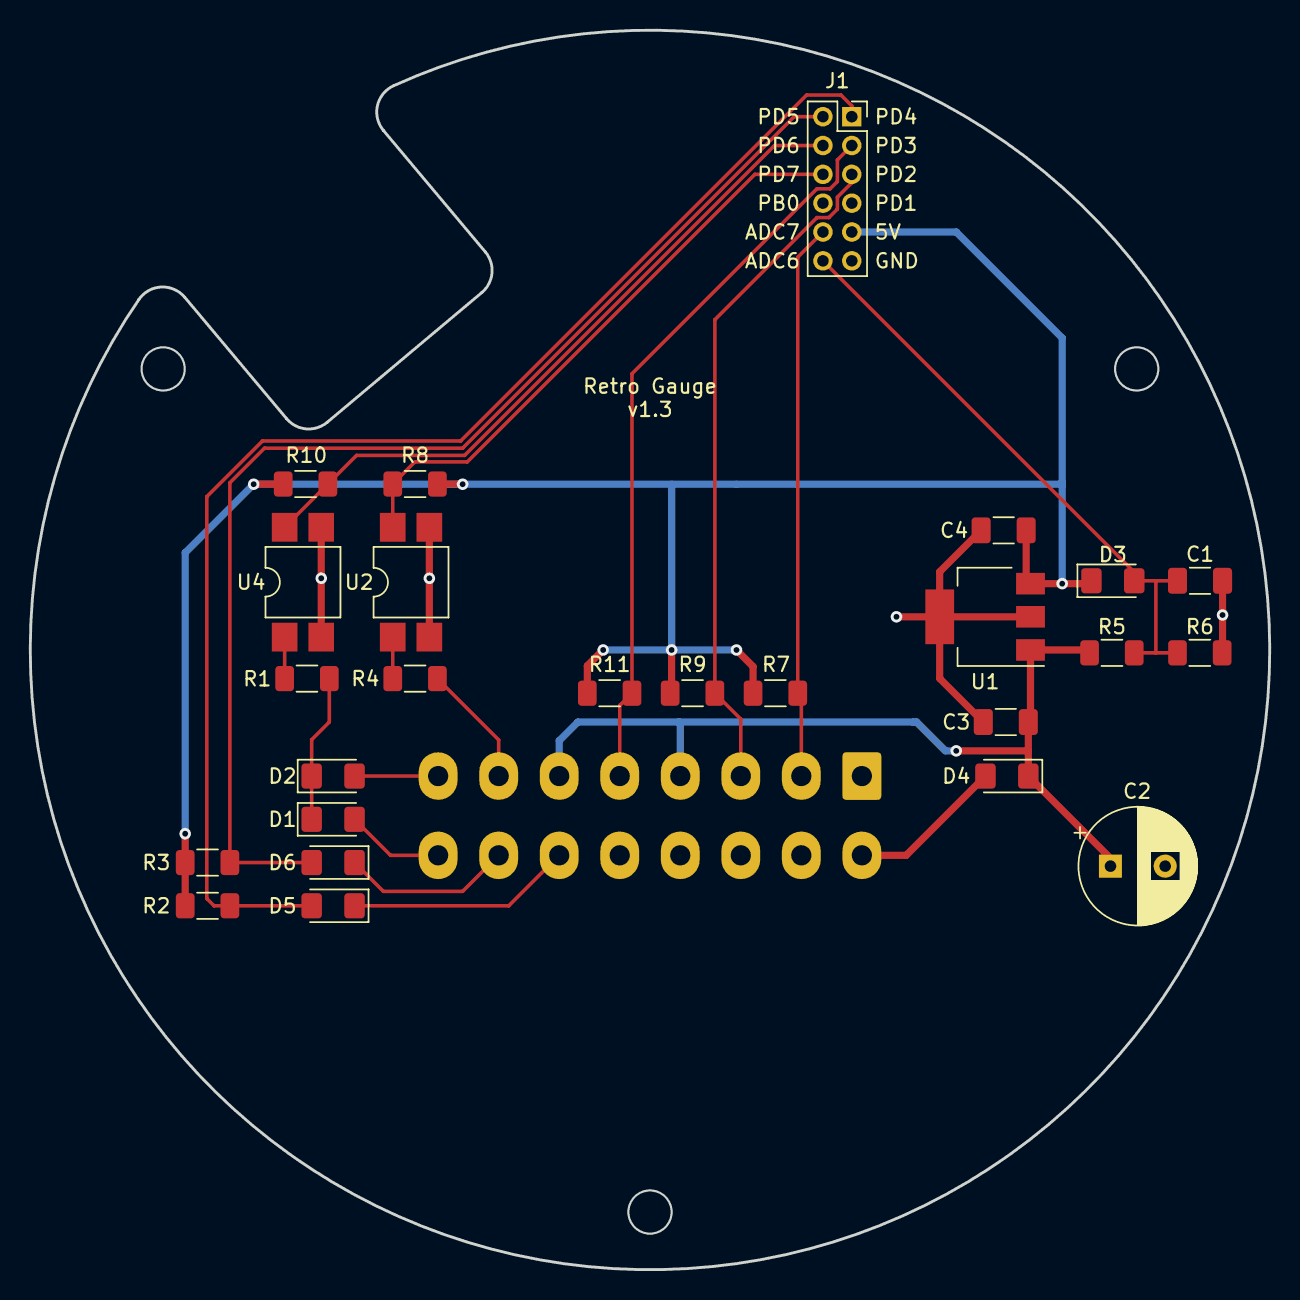
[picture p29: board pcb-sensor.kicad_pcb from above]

Board: 2 copper layers, 86.0 x 86.0 mm, 26 parts (1 on the bottom side), 20 nets.

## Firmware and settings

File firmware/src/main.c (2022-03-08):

#include <avr/io.h>
#include <util/delay.h>
#include <util/atomic.h>
#include <stdint.h>
#include <stdio.h>

#include "button.h"
#include "eeprom.h"
#include "twi.h"
#include "rtc.h"
#include "analog.h"
#include "timer.h"
#include "led.h"
#include "lcd.h"
#include "motor.h"
#include "config.h"

#include "mode.h"

#include "speedo.h"
#include "indicators.h"
#include "battery.h"
#include "clock.h"

Mode mode = SPEED;
uint32_t modeSwitchTime;

void init();
void update();
void display();

int main() {
    init();

    while (1) {
        update();
        display();
    }

    return 0;
}

void init() {
    sei();

    initTwi();
    initTimer();
    initAnalog();
    initLed();
    initLcd();
    initMotor();
    initButton();

    initIndicators();
    initSpeedo();
}

void update() {
    updateButton();
    updateMotor();
    updateIndicators();

    updateBatteryVoltage();
    updateSpeedo(mode);
    updateClock(mode);

    if (consumeShortButtonPress() == BUTTON_DOWN) {
        mode = (mode + 1) % NUMBER_OF_MODES;
        modeSwitchTime = millis();
    }
}

void display() {
    if (millis() - modeSwitchTime < 1000) {
        switch (mode) {
            case BATTERY:
                lcdDisplayString("Battery ");
                break;
            case SPEED:
                lcdDisplayString("Speed   ");
                break;
            case ODO:
                lcdDisplayString("Odo     ");
                break;
            case TRIP:
                lcdDisplayString("Trip    ");
                break;
            case CLOCK:
                lcdDisplayString("Clock   ");
                break;
            default:
                break;
        }
    } else {
        switch (mode) {
            case BATTERY:
                displayBattery();
                break;
            case SPEED:
                displaySpeed();
                break;
            case ODO:
                displayOdo();
                break;
            case TRIP:
                displayTrip();
                break;
            case CLOCK:
                displayClock();
                break;
            default:
                break;
        }
    }
}

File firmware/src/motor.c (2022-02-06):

#include <avr/io.h>
#include <stdint.h>

#include "motor.h"
#include "timer.h"

#define MOT_PORT    PORTC
#define MOT_DDR     DDRC
#define MOT_1_MASK  (1 << PC1)
#define MOT_2_MASK  (1 << PC0)
#define MOT_3_MASK  (1 << PC3)
#define MOT_4_MASK  (1 << PC2)

#define MOT_PATTERN_4 0b00000111
#define MOT_PATTERN_3 0b00011100
#define MOT_PATTERN_2 0b00011100
#define MOT_PATTERN_1 0b00110001

#define STEP_PERIOD 1000

#define MAX_POSITION        12
#define STEPS_PER_POSITION  60.
#define MAX_STEPS           (STEPS_PER_POSITION * MAX_POSITION)

uint32_t lastStepTime = 0;
uint16_t currentSteps = 0;
uint16_t targetSteps = 0;

void waitForMotor();
void stepMotor();

void initMotor() {
    MOT_DDR |= MOT_1_MASK;
    MOT_DDR |= MOT_2_MASK;
    MOT_DDR |= MOT_3_MASK;
    MOT_DDR |= MOT_4_MASK;

    // Home the motor
    setMotorTargetPosition(MAX_POSITION);
    waitForMotor();
    setMotorTargetPosition(0);
    waitForMotor();
}

void setMotorTargetPosition(float position) {
    targetSteps = position * STEPS_PER_POSITION;
    if (targetSteps > MAX_STEPS) {
        targetSteps = MAX_STEPS;
    }
    if (targetSteps < 0) {
        targetSteps = 0;
    }
}

float getMotorCurrentPosition() {
    return currentSteps / STEPS_PER_POSITION;
}

void updateMotor() {
    uint32_t currentTime = micros();
    if (currentTime - lastStepTime >= STEP_PERIOD) {
        int16_t delta = targetSteps - currentSteps;
        int8_t direction = (delta > 0) - (delta < 0);

        currentSteps += direction;

        stepMotor();

        lastStepTime = currentTime;
    }
}

void waitForMotor() {
    while (currentSteps != targetSteps) {
        updateMotor();
    }
}

void stepMotor() {
    uint8_t step = currentSteps % 6;

    if ((MOT_PATTERN_1 >> step) & 1)
        MOT_PORT |= MOT_1_MASK;
    else
        MOT_PORT &= ~MOT_1_MASK;

    if ((MOT_PATTERN_2 >> step) & 1)
        MOT_PORT |= MOT_2_MASK;
    else
        MOT_PORT &= ~MOT_2_MASK;

    if ((MOT_PATTERN_3 >> step) & 1)
        MOT_PORT |= MOT_3_MASK;
    else
        MOT_PORT &= ~MOT_3_MASK;

    if ((MOT_PATTERN_4 >> step) & 1)
        MOT_PORT |= MOT_4_MASK;
    else
        MOT_PORT &= ~MOT_4_MASK;
}

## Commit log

2021-09-04 updated circuit for spike
    [mcu-circuit.sch]
2021-09-10 lcd and mcu
    [lcd-circuit.kicad_pcb, lcd-circuit.sch, lcd.sch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]
2021-09-18 added stepper motor spike (and heaps of other stuff)
    [lcd-circuit.kicad_pcb, mcu-circuit.kicad_pcb, pcb-face.kicad_pcb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]
2021-09-18 cleaned up main pcb
    [pcb-main.kicad_pcb, pcb-main.sch]
2021-09-19 sensor pcb
    [pcb-sensor.kicad_pcb, pcb-sensor.sch]
2021-10-10 initial case 3d model
    [case-Body.stl, case-Face.stl, case.FCStd]
2021-10-16 add tacho sensor circuit
    [tacho-sensor.kicad_pcb, tacho-sensor.sch]
2021-10-16 updated case 3d model
    [case.FCStd]
2021-10-16 add oshw logo
    [pcb-face.kicad_pcb, pcb-main.kicad_pcb, pcb-sensor.kicad_pcb]
2021-11-09 made pcb bigger
    [case.FCStd, pcb-face.kicad_pcb, pcb-main.kicad_pcb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]
2021-11-09 reset button label
    [pcb-main.kicad_pcb]
2021-11-27 started v1.1
    [case-Body.stl, case-Face.stl, case.FCStd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]
2021-11-27 more v1.1
    [pcb-sensor.kicad_pcb, pcb-sensor.sch, pcb-tacho.kicad_pcb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]
2021-12-29 led and lcd code
2021-12-29 motor codez
    [pcb-main.kicad_sch, pcb-sensor.sch]
2021-12-30 migrate to kicad 6
    [pcb-face.kicad_pcb, pcb-main.kicad_pcb, pcb-sensor.kicad_pcb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]
2021-12-30 battery voltage
2022-01-29 led shield
    [case-Body.stl, case-Face.stl, case.FCStd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]
2022-01-29 tacho sensor pcb
    [pcb-tacho.kicad_pcb, pcb-tacho.kicad_sch]
2022-01-29 removed spikes
    [lcd-circuit.sch, mcu-circuit.sch, stepper-circuit.sch]
2022-02-05 mode button
2022-02-05 clean up
    [pcb-main.kicad_sch]
2022-03-05 simplified the speedo code
    [pcb-sensor.kicad_sch]
2022-03-06 resolves #32: warning indicator symbol
    [pcb-face.kicad_pcb]
2022-03-06 resolves #29: move needle pin
    [pcb-face.kicad_pcb]
2022-03-06 resolves #22: see through indicator icons
    [pcb-face.kicad_pcb]
2022-03-06 resolves #27: move rtc capacitor closer to ic
    [pcb-main.kicad_pcb]
2022-03-06 resolves #30: odo in eeprom
    [main.c, speedo.c]
2022-03-06 resolves #35: 32bit odo
    [speedo.c]
2022-03-06 resolves #34: eeprom rotation
    [main.c, speedo.c]
2022-03-06 resolves #21: reset button
    [pcb-main.kicad_pcb, pcb-main.kicad_sch]
2022-03-08 resolves #31: set clock time
    [main.c, speedo.c]
2022-03-11 resolves #37: optocoupler footprint
    [pcb-sensor.kicad_pcb, pcb-sensor.kicad_sch]
2022-03-13 model cleanup
    [case.FCStd]
2022-03-13 3d model assembly
    [case-Body.stl, case-Face.stl, case-assembly.FCStd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]
2022-09-10 resolves #43: reduce hall effect sensor pull up to remove noise
    [pcb-sensor.kicad_sch]
2022-09-11 remove kicad 4 files
    [pcb-main.sch, pcb-sensor.sch, pcb-tacho.sch]
2022-09-11 resolves #13: lcd brightness pot
    [pcb-main.kicad_pcb, pcb-main.kicad_sch]
2022-09-17 resolves #40: fix 3d models
    [pcb-main.kicad_pcb, pcb-sensor.kicad_pcb, pcb-tacho.kicad_pcb]
2022-09-17 resolves #39: smd crystals
    [pcb-main.kicad_pcb, pcb-main.kicad_sch]
2022-09-17 resolves #18: integrated mode button
    [pcb-main.kicad_pcb]
2022-09-17 resolves #26: protection diodes
    [pcb-main.kicad_pcb, pcb-sensor.kicad_pcb, pcb-sensor.kicad_sch]
2022-09-17 resolves #17: interrupt pin
    [pcb-sensor.kicad_pcb, pcb-sensor.kicad_sch]
2022-09-17 changed pot
    [pcb-main.kicad_pcb, pcb-main.kicad_sch]
2022-09-17 resolves #47: update silkscreen labels
    [pcb-face.kicad_pcb, pcb-main.kicad_pcb, pcb-sensor.kicad_pcb]
2022-09-17 resolves #46: mode button connector
    [pcb-sensor.kicad_pcb, pcb-sensor.kicad_sch]
2022-10-01 led indicator cleanup
2022-10-09 deleted tacho
    [pcb-tacho.kicad_pcb, pcb-tacho.kicad_sch]
2022-10-09 changed lcd resistor to 100k
    [pcb-main.kicad_sch]
2022-10-14 resolves #52: crystal circuit
    [pcb-face.kicad_pcb, pcb-main.kicad_pcb, pcb-main.kicad_sch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]
2022-10-15 resolves #48: neopixel caps
    [pcb-main.kicad_pcb, pcb-main.kicad_sch]
2022-10-15 pcb cleanup
    [pcb-main.kicad_pcb]
2022-10-28 update layout
    [pcb-main.kicad_pcb, pcb-main.kicad_sch, pcb-outline.FCStd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]
2022-10-30 update pcb layouts
    [pcb-main.kicad_pcb, pcb-main.kicad_sch, pcb-sensor.kicad_pcb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]
2022-11-13 v1.3 last minute changes
    [pcb-face.kicad_pcb, pcb-main.kicad_pcb, pcb-main.kicad_sch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]
2023-02-04 updated pcb outline
    [pcb-outline.FCStd]
2023-02-04 new case design
    [case.FCStd]
